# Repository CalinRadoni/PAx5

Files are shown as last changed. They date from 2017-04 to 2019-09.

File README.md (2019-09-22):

# PAx5

## Note

This repository is archived because I am building a version with better integration
in the [pax-devices](https://github.com/CalinRadoni/pax-devices) repository.

## Description

__PAx5__ is a home automation platform designed to be secure, stable and powerful.

__#__ Hardware is centered around an ultra-low-power ARM Cortex-M0+ and a sub-GHz radio.

__#__ For security:
- AEAD (_Authenticated Encryption with Associated Data_) using the 128 or 256 bits key ChaCha20 algorithm (the _new_ protocol used in HTTPS, TLS, OpenSSL, ...);
- Unique, random, session keys;
- Communication protocol designed to withstand the known attacks against these type of communications.

__#__ Stability is increased with:
- the radio module's power is generally enough to not require intermediary routers;
- designed for high availability, redundant, gateways.

### Dependencies

CMSIS

### Hardware details

MCU: STM32L051xx
Radio: RFM69HW
SPI FLASH Memory

Rendering and pinouts are in `Docs/PAx5_Base` and in `Docs/PAx5_EnvSensor`.

Environment sensor rendering:
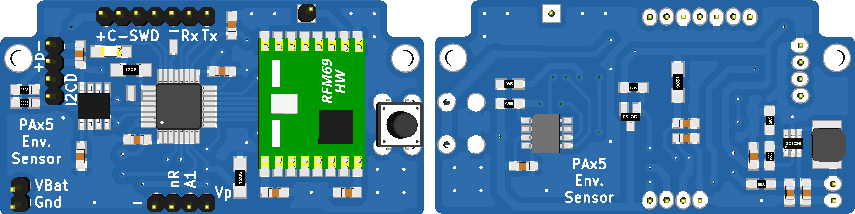
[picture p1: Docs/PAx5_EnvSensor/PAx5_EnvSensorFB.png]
env-sensor


and a photo of the sensor and base board:
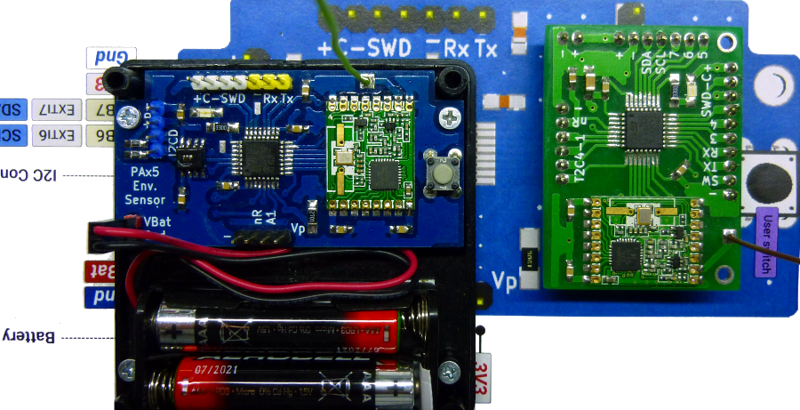
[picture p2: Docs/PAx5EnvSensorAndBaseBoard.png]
env-sensor


### Development Environment

Main tools used are:
- [KiCad EDA](http://kicad-pcb.org/)
- [Atollic TrueSTUDIO](https://atollic.com/truestudio/) Free Edition
- [Atom](https://atom.io/) editor

Supplementary tools:
- [Git](https://git-scm.com/)
- [STM32CubeMX](http://www.st.com/en/development-tools/stm32cubemx.html)
- [Inkscape](https://inkscape.org/en/)

### License

PAx5's software and documentation is released under the [GNU GPLv3](http://www.gnu.org/licenses/gpl-3.0.html) License. See the __LICENSE-GPLv3.txt__ file.

PAx5's hardware schematics are licensed under a [Creative Commons Attribution-ShareAlike 4.0 International License](http://creativecommons.org/licenses/by-sa/4.0/).
See the __LICENSE-CC-BY-SA-4.0.txt__ file.

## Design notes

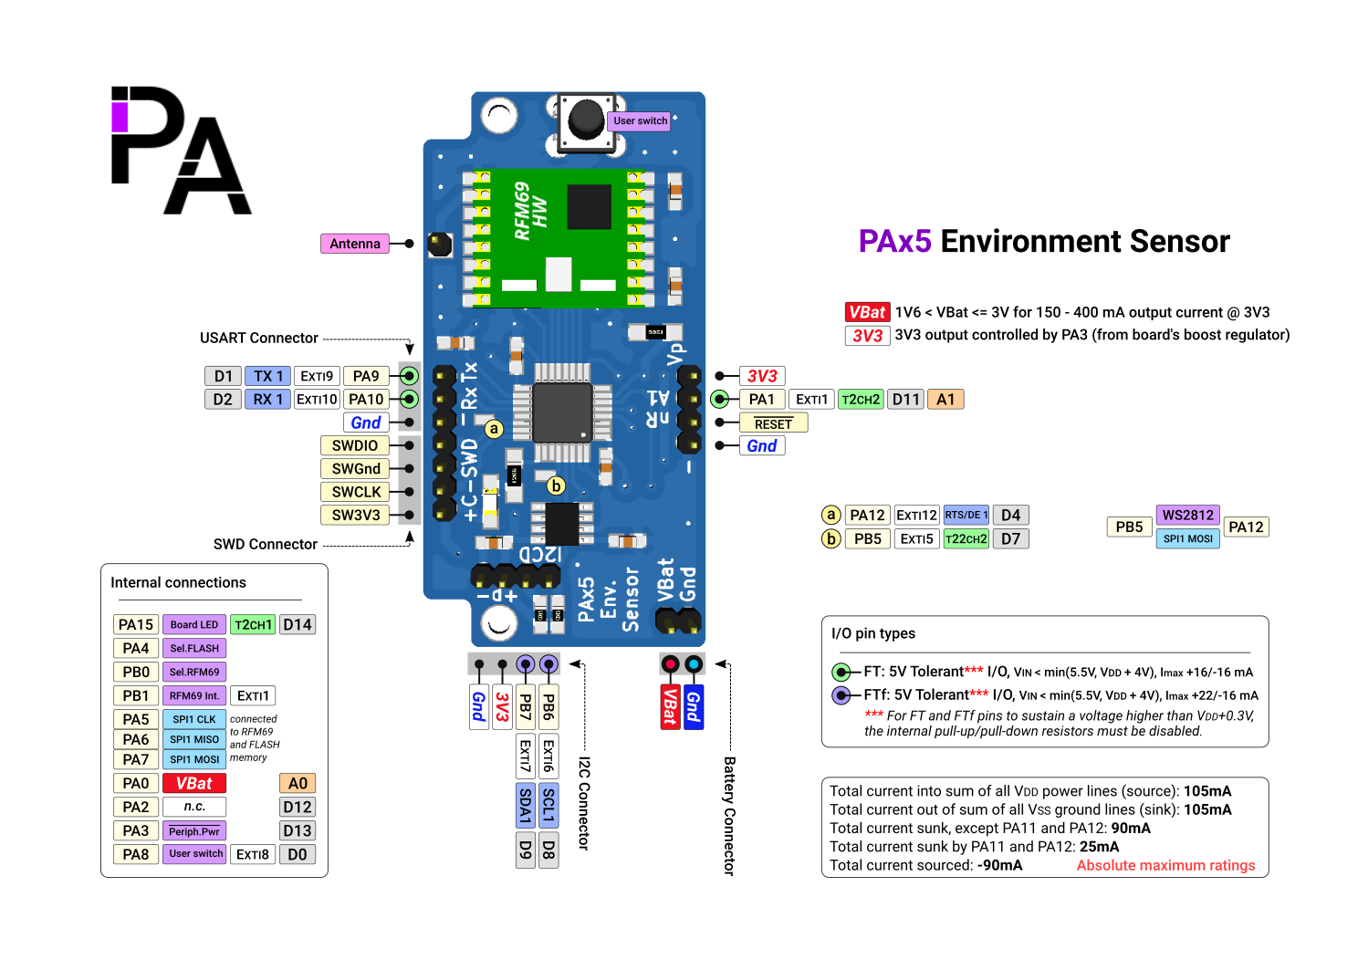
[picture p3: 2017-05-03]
Docs/PAx5_EnvSensor/PAx5_EnvSensor_Pinout.png

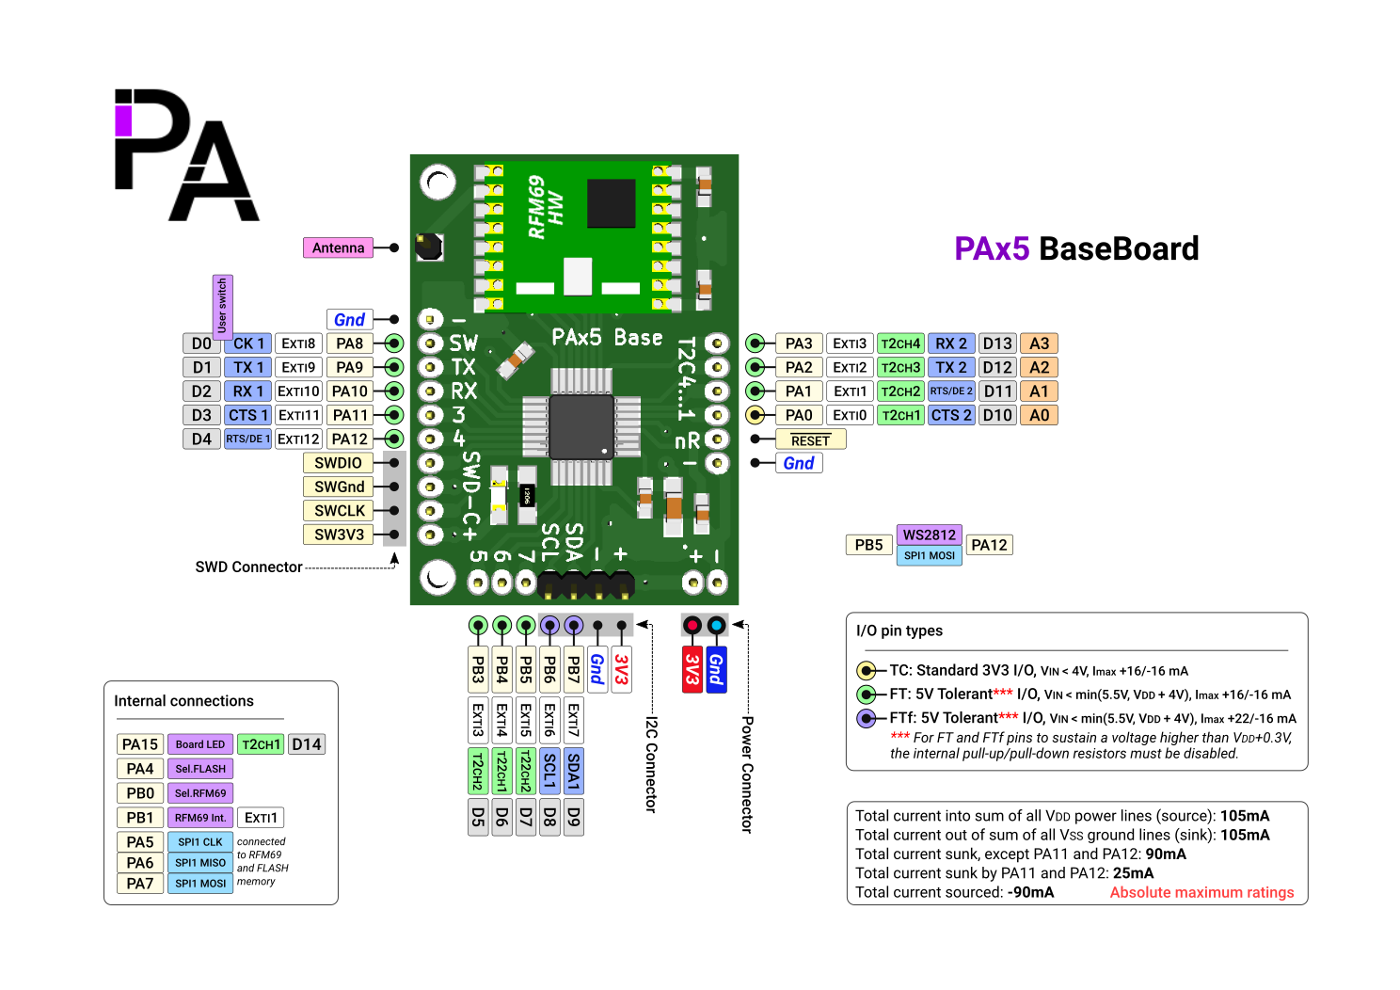
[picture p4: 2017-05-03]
Docs/PAx5_Base/PAx5_Base_Pinout.png

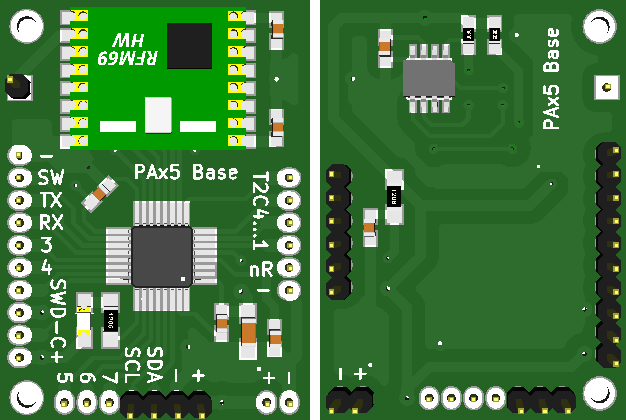
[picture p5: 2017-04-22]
Docs/PAx5_Base/PAx5_BaseFB.png

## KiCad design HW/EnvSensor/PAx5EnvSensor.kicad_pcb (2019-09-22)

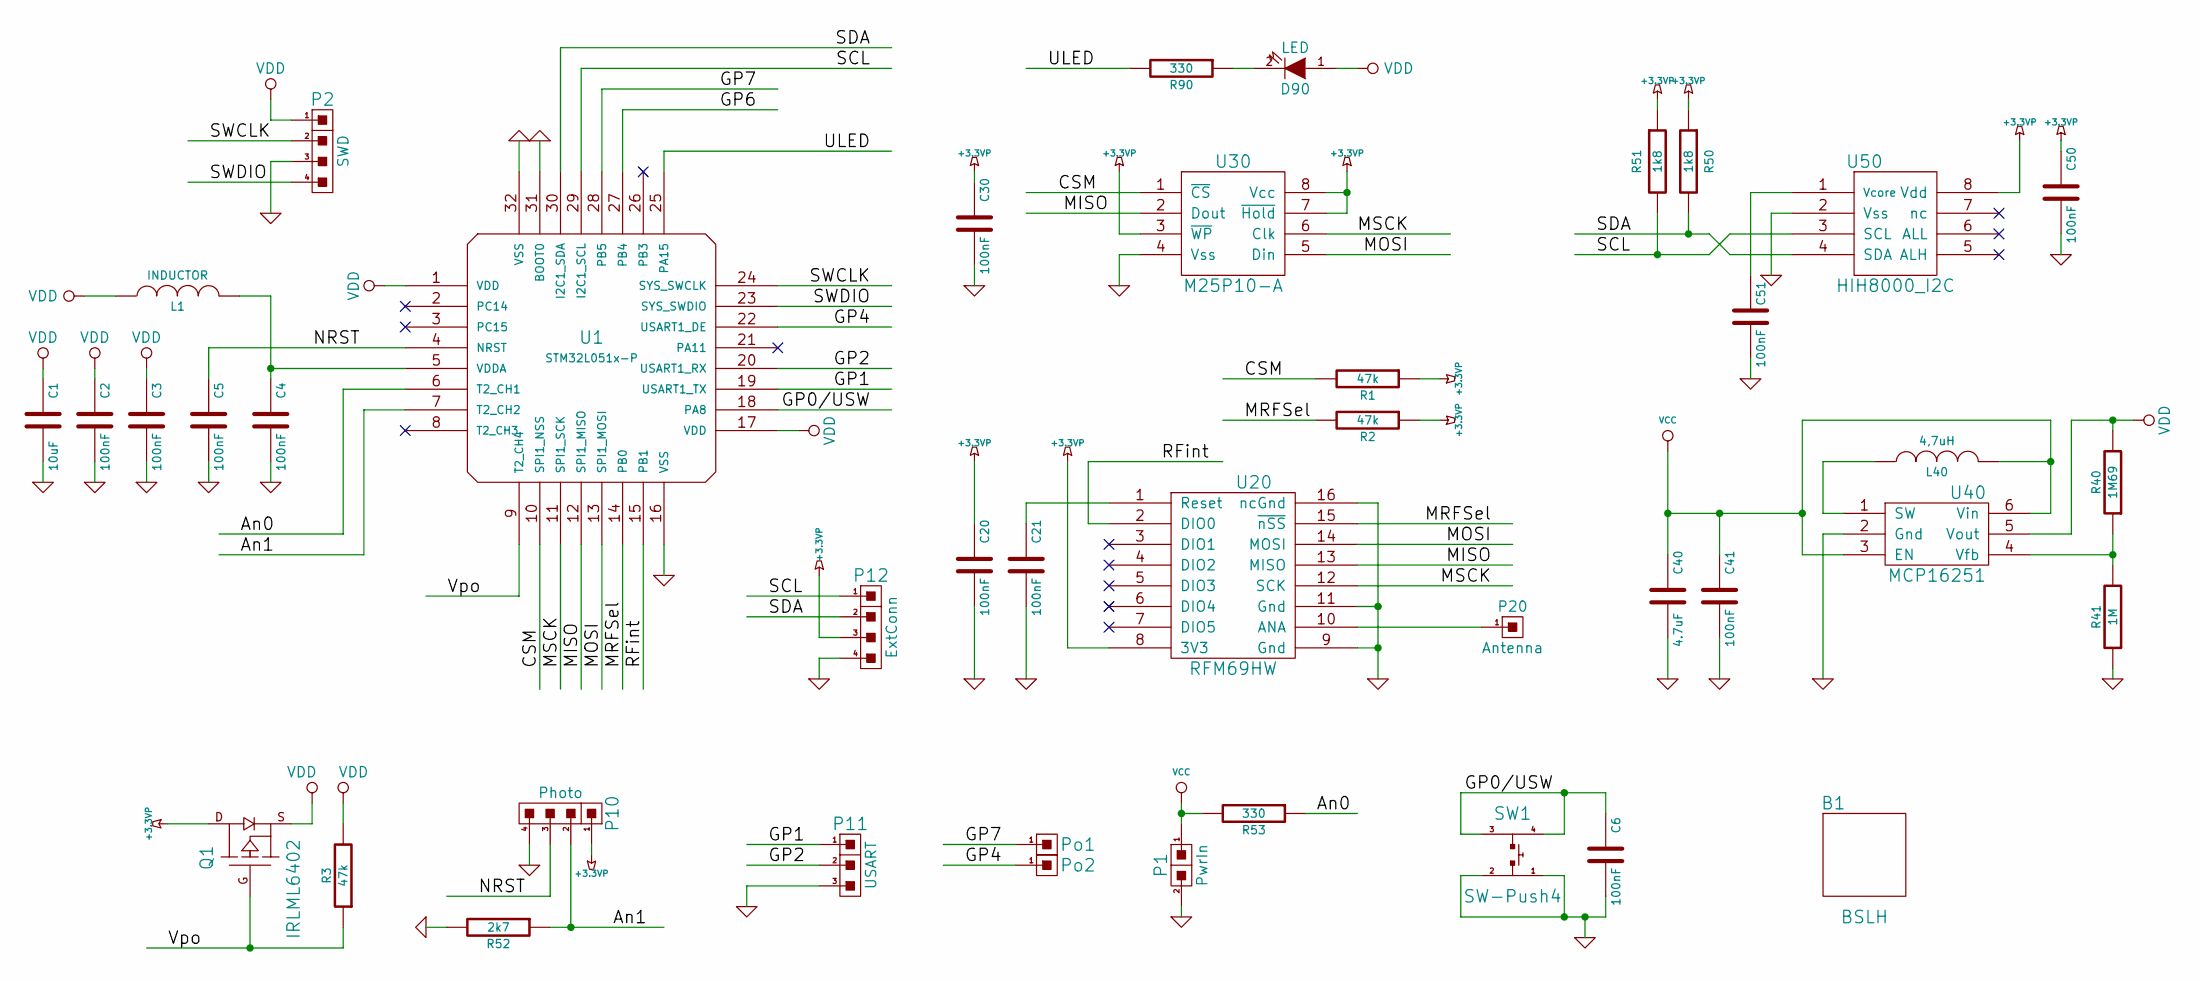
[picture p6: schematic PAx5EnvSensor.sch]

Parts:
B1: BSLH; Box-Sens-LH-NPTH
C1: 10uF; C_0805_HandSoldering
C2, C3, C4, C5, C6, C20, C21, C30, C41, C50, C51: 100nF; C_0805_HandSoldering
C40: 4.7uF; C_0805_HandSoldering
D90: LED; LED_1206_HandSoldering
L1: INDUCTOR; R_1206_HandSoldering
L40: 4,7uH; TYS50xx
P1: PwrIn; Pin_Header_Straight_1x02
P2: SWD; Pin_Header_Straight_1x04
P10: Photo; Pin_Header_Straight_1x04
P11: USART; Pin_Header_Straight_1x03
P12: ExtConn; Pin_Header_Straight_1x04
P20: Antenna; Pin_Header_Straight_1x01
Po1, Po2: PinTest-SMD
Q1: IRLML6402; SOT-23-calin
R1, R2, R3: 47k; R_0805_HandSoldering
R40: 1M69; R_0805_HandSoldering
R41: 1M; R_0805_HandSoldering
R50, R51: 1k8; R_0805_HandSoldering
R52: 2k7; R_1206_HandSoldering
R53: 330; R_0805_HandSoldering
R90: 330; R_1206_HandSoldering
SW1: SW-Push4; cSW-Push-4
U1: STM32L051x-P; cLQFP32-7-v2
U20: RFM69HW
U30: M25P10-A; SOIC-8-N
U40: MCP16251; SOT23-6
U50: HIH8000_I2C; HIH8000

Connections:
+3.3VP: C20.1, C30.1, C50.1, P10.1, P12.3, Q1.D, R1.1, R2.1, R50.1, R51.1, U20.8 (3V3), U30.3 (~WP), U30.7 (~Hold), U30.8 (Vcc), U50.8 (Vdd)
/An0: R53.1, U1.6 (T2_CH1)
/An1: P10.2, R52.1, U1.7 (T2_CH2)
/CSM: R1.2, U1.10 (SPI1_NSS), U30.1 (~CS)
/GP0/USW: C6.1, SW1.3, SW1.4, U1.18 (PA8)
/GP1: P11.1, U1.19 (USART1_TX)
/GP2: P11.2, U1.20 (USART1_RX)
/GP4: Po2.1, U1.22 (USART1_DE)
/GP7: Po1.1, U1.28 (PB5)
/MISO: U1.12 (SPI1_MISO), U20.13 (MISO), U30.2 (Dout)
/MOSI: U1.13 (SPI1_MOSI), U20.14 (MOSI), U30.5 (Din)
/MRFSel: R2.2, U1.14 (PB0), U20.15 (~nSS)
/MSCK: U1.11 (SPI1_SCK), U20.12 (SCK), U30.6 (Clk)
/NRST: C5.1, P10.3, U1.4 (NRST)
/RFint: U1.15 (PB1), U20.2 (DIO0)
/SCL: P12.1, R51.2, U1.29 (I2C1_SCL), U50.3 (SCL)
/SDA: P12.2, R50.2, U1.30 (I2C1_SDA), U50.4 (SDA)
/SWCLK: P2.2, U1.24 (SYS_SWCLK)
/SWDIO: P2.4, U1.23 (SYS_SWDIO)
/ULED: R90.2, U1.25 (PA15)
/Vpo: Q1.G, R3.1, U1.9 (T2_CH4)
GND: C1.2, C2.2, C3.2, C4.2, C5.2, C6.2, C20.2, C21.2, C30.2, C40.2, C41.2, C50.2, C51.2, P1.2, P2.3, P10.4, P11.3, P12.4, R41.1, R52.2, SW1.1, SW1.2, U1.16 (VSS), U1.31 (BOOT0), U1.32 (VSS), U20.9 (Gnd), U20.11 (Gnd), U20.16 (ncGnd), U30.4 (Vss), U40.2 (Gnd), U50.2 (Vss)
unnamed: C4.1, L1.2, U1.5 (VDDA)
unnamed: C21.1, U20.1 (Reset)
unnamed: C51.1, U50.1 (Vcore)
unnamed: D90.2 (K), R90.1
unnamed: L40.1, U40.1 (SW)
unnamed: P20.1, U20.10 (ANA)
unnamed: R40.1, R41.2, U40.4 (Vfb)
VCC: C40.1, C41.1, L40.2, P1.1, R53.2, U40.3 (EN), U40.6 (Vin)
VDD: C1.1, C2.1, C3.1, D90.1 (A), L1.1, P2.1, Q1.S, R3.2, R40.2, U1.1 (VDD), U1.17 (VDD), U40.5 (Vout)

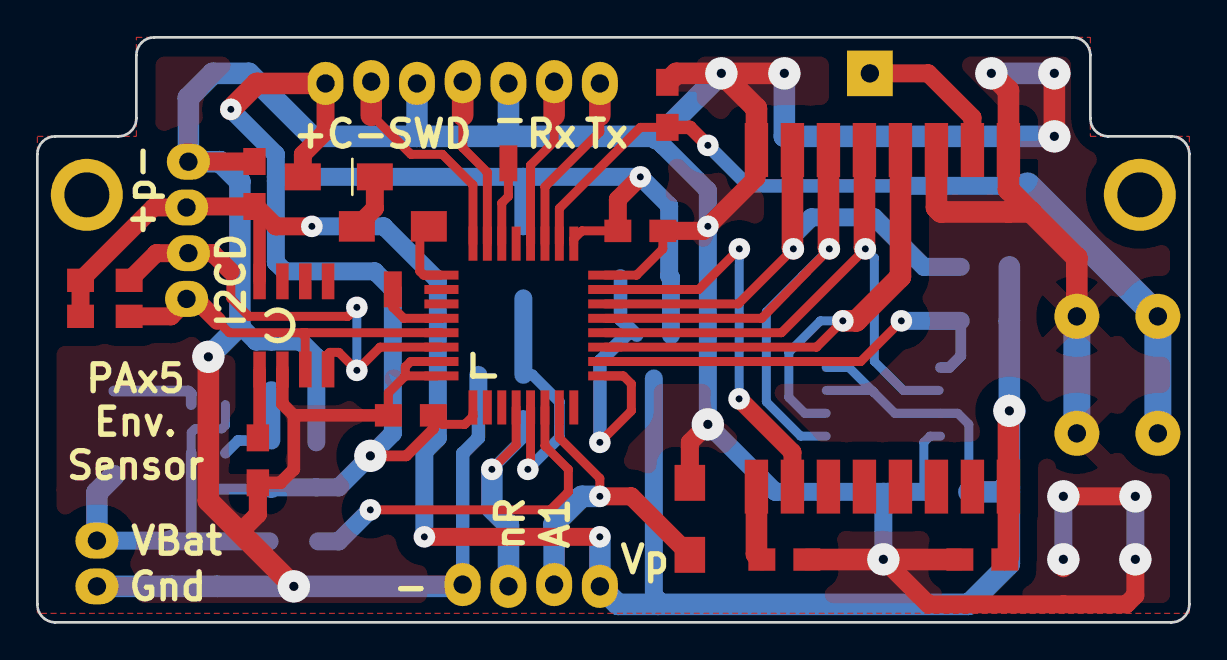
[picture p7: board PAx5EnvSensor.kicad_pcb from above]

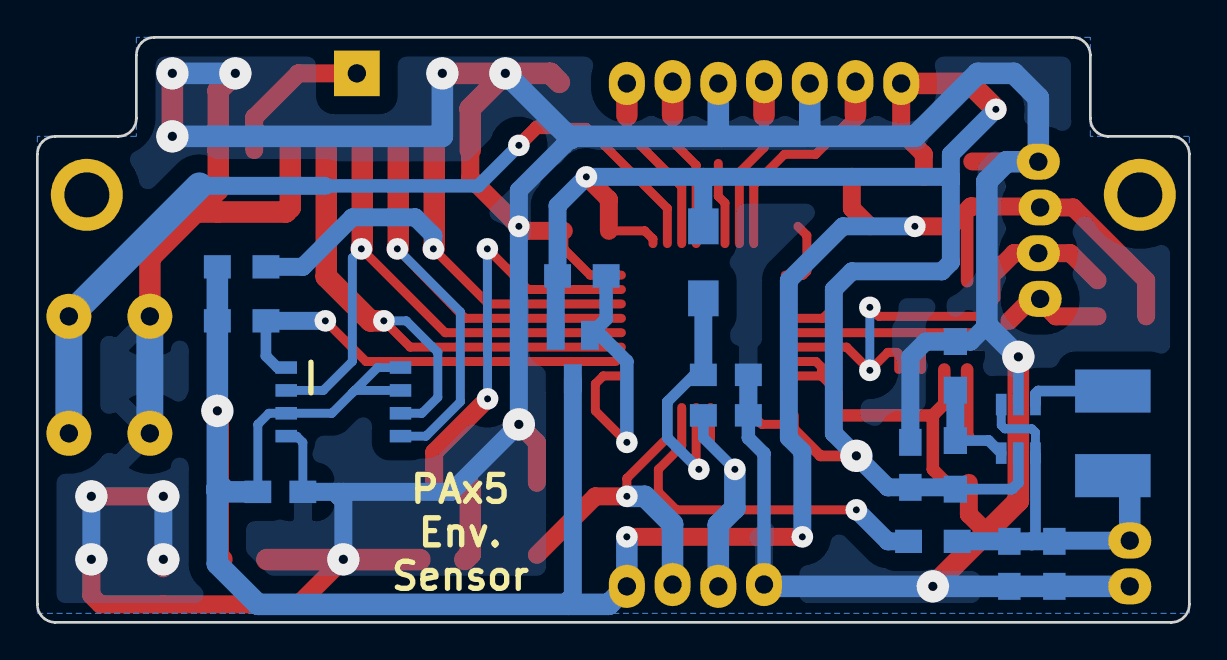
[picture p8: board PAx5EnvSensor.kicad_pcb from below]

Board: 2 copper layers, 64.0 x 32.5 mm, 42 parts (17 on the bottom side), 31 nets.

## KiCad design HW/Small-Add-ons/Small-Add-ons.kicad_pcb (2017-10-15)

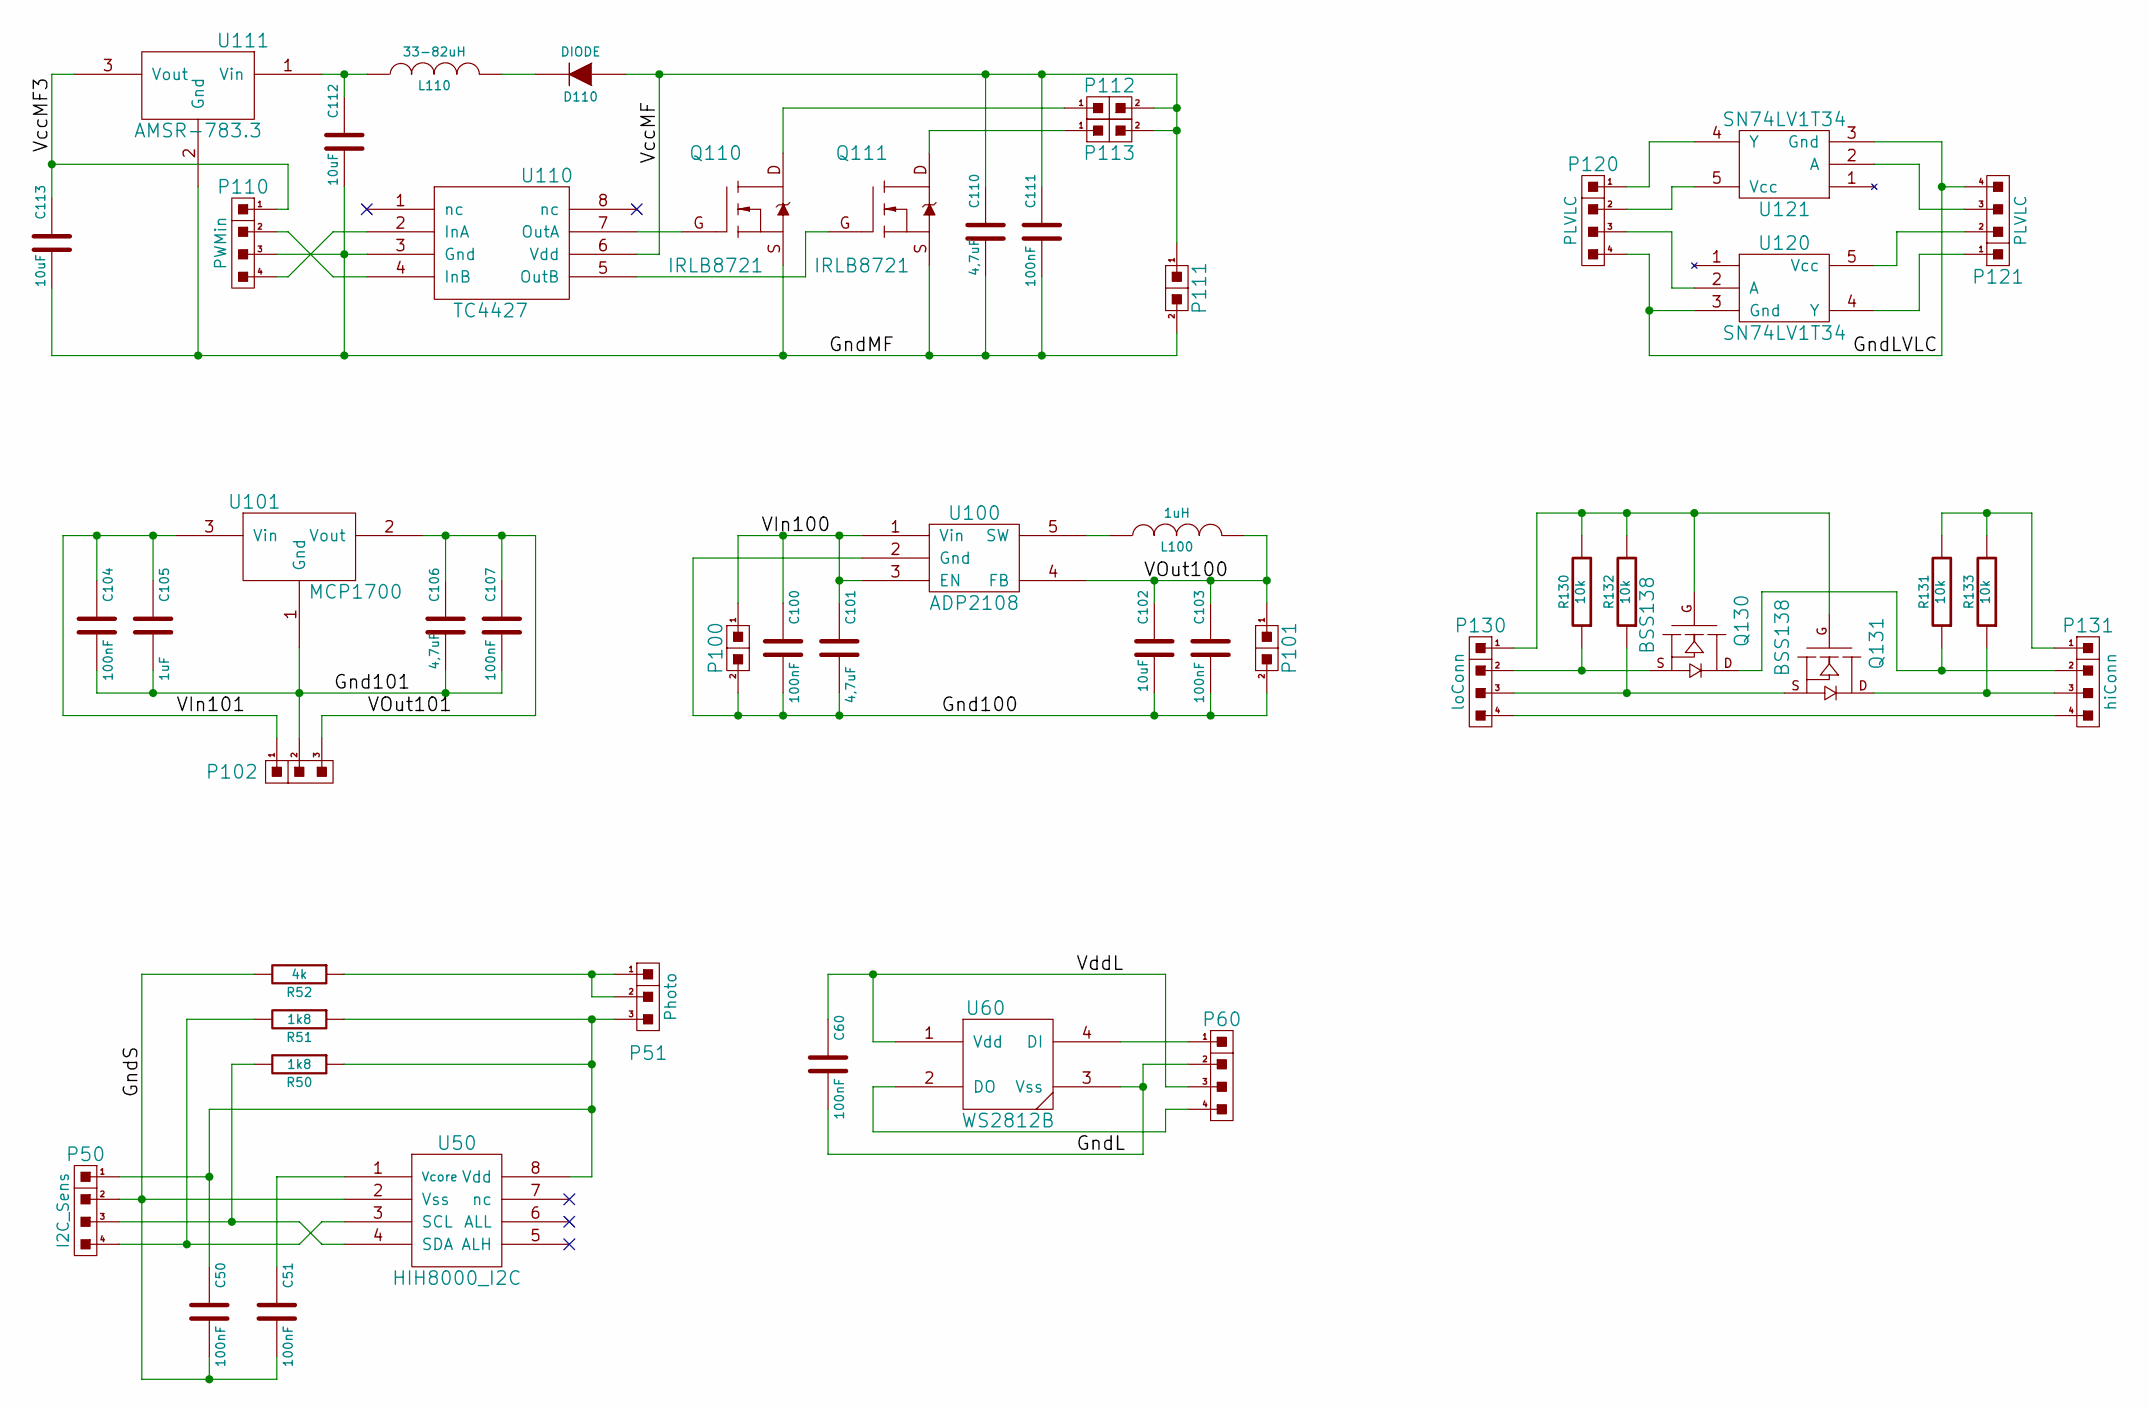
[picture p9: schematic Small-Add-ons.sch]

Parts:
C50, C51, C60, C100, C103, C104, C107, C111: 100nF; C_0805_HandSoldering
C101, C106, C110: 4,7uF; C_0805_HandSoldering
C102: 10uF; C_0805_HandSoldering
C105: 1uF; C_0805_HandSoldering
C112, C113: 10uF; C_1206_HandSoldering
D110: DIODE; DO-214AA-12
L100: 1uH; muRata-LQM2HPN1R0MJ0
L110: 33-82uH; COIL0608-0.033
P50: I2C_Sens; Pin_Header_Straight_1x04
P51: Photo; Pin_Header_Straight_1x03
P60: Pin_Header_Straight_1x04
P100: PVIn; Pin_Header_Straight_1x02
P101: PVOut; Pin_Header_Straight_1x02
P102: Pin_Header_Straight_1x03
P110: PWMin; Pin_Header_Straight_1x04
P111, P112, P113: PVOut; bornier2
P120, P121: PLVLC; Pin_Header_Straight_1x04
P130: loConn; Pin_Header_Straight_1x04
P131: hiConn; Pin_Header_Straight_1x04
Q110, Q111: IRLB8721; TO-220AB-GDS
Q130, Q131: BSS138; SOT-23-calin
R50, R51: 1k8; R_0805_HandSoldering
R52: 4k; R_1206_HandSoldering
R130, R131, R132, R133: 10k; R_0805_HandSoldering
U50: HIH8000_I2C; HIH8000
U60: WS2812B
U100: ADP2108; SOT23-5
U101: MCP1700; SOT23
U110: TC4427; SOIC-8-N
U111: AMSR-783.3; TO-220AB(SOT78)
U120, U121: SN74LV1T34; SOT23-5

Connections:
/Gnd100: C100.2, C101.2, C102.2, C103.2, P100.2, P101.2, U100.2 (Gnd)
/Gnd101: C104.2, C105.2, C106.2, C107.2, P102.2, U101.1 (Gnd)
/GndL: C60.2, P60.2, U60.3 (Vss)
/GndLVLC: P120.4, P121.4, U120.3 (Gnd), U121.3 (Gnd)
/GndMF: C110.2, C111.2, C112.2, C113.2, P110.3, P111.2, Q110.S, Q111.S, U110.3 (Gnd), U111.2 (Gnd)
/GndS: C50.2, C51.2, P50.2, R52.2, U50.2 (Vss)
/VIn100: C100.1, C101.1, P100.1, U100.1 (Vin), U100.3 (EN)
/VIn101: C104.1, C105.1, P102.1, U101.3 (Vin)
/VOut100: C102.1, C103.1, L100.2, P101.1, U100.4 (FB)
/VOut101: C106.1, C107.1, P102.3, U101.2 (Vout)
/VccMF: C110.1, C111.1, D110.1 (A), P111.1, P112.2, P113.2, U110.6 (Vdd)
/VccMF3: C113.1, P110.1, U111.3 (Vout)
/VddL: C60.1, P60.3, U60.1 (Vdd)
unnamed: C50.1, P50.1, P51.3, R50.1, R51.1, U50.8 (Vdd)
unnamed: C51.1, U50.1 (Vcore)
unnamed: C112.1, L110.1, U111.1 (Vin)
unnamed: D110.2 (K), L110.2
unnamed: L100.1, U100.5 (SW)
unnamed: P50.3, R50.2, U50.4 (SDA)
unnamed: P50.4, R51.2, U50.3 (SCL)
unnamed: P51.1, P51.2, R52.1
unnamed: P60.1, U60.4 (DI)
unnamed: P60.4, U60.2 (DO)
unnamed: P110.2, U110.4 (InB)
unnamed: P110.4, U110.2 (InA)
unnamed: P112.1, Q110.D
unnamed: P113.1, Q111.D
unnamed: P120.1, U121.4 (Y)
unnamed: P120.2, U121.5 (Vcc)
unnamed: P120.3, U120.2 (A)
unnamed: P121.1, U120.4 (Y)
unnamed: P121.2, U120.5 (Vcc)
unnamed: P121.3, U121.2 (A)
unnamed: P130.1, Q130.G, Q131.G, R130.2, R132.2
unnamed: P130.2, Q130.S, R130.1
unnamed: P130.3, Q131.S, R132.1
unnamed: P130.4, P131.4
unnamed: P131.1, R131.2, R133.2
unnamed: P131.2, Q130.D, R131.1
unnamed: P131.3, Q131.D, R133.1
unnamed: Q110.G, U110.7 (OutA)
unnamed: Q111.G, U110.5 (OutB)

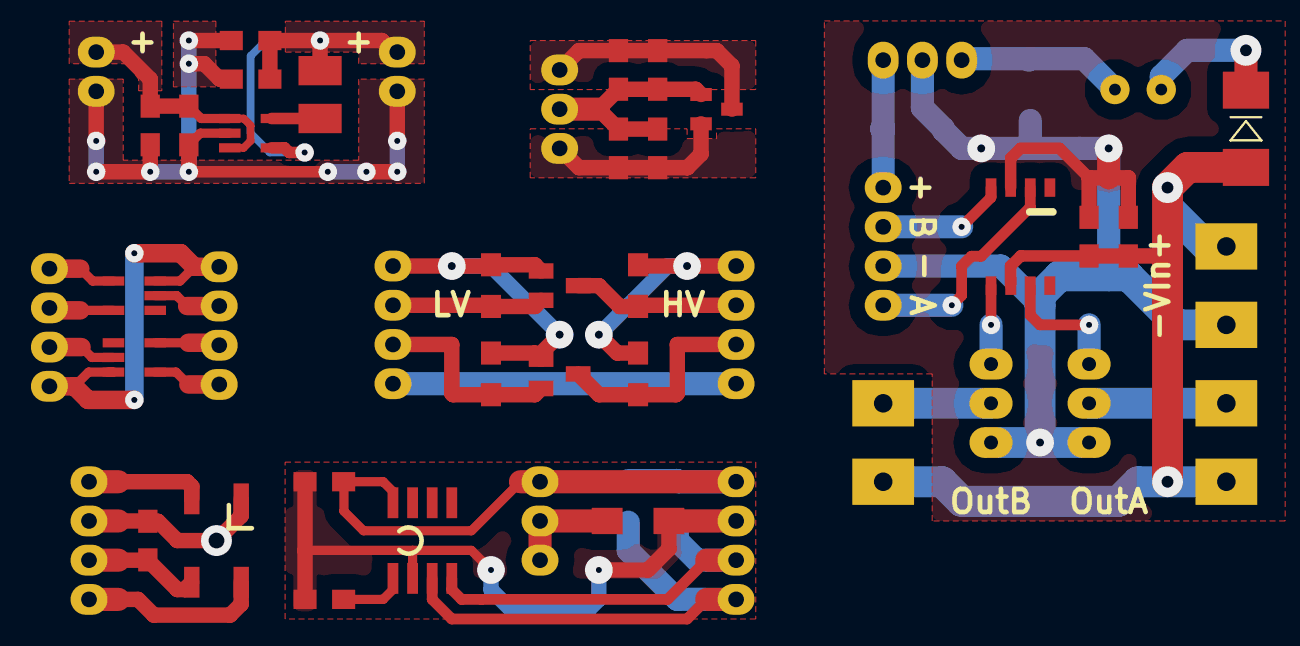
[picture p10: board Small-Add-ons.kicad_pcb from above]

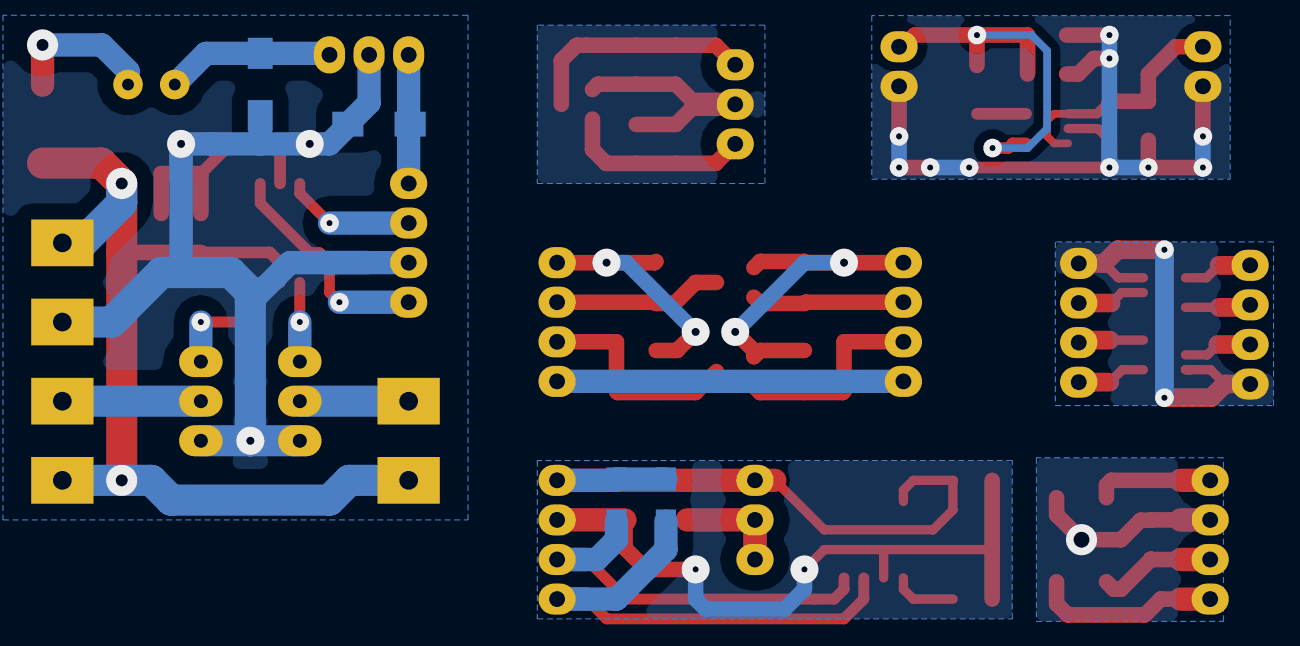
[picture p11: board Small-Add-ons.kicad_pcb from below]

Board: 2 copper layers, 51 parts (9 on the bottom side), 42 nets.

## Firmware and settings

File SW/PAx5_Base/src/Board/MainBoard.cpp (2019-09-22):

/**
This file is part of PAx5 (https://github.com/CalinRadoni/PAx5)
Copyright (C) 2016, 2017 by Calin Radoni

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
You should have received a copy of the GNU General Public License
along with this program.  If not, see <http://www.gnu.org/licenses/>.
*/

#include "MainBoard.h"

#include "cpu_Core.h"
#include "cpu_USART1.h"
#include "cpu_Info.h"
#include "cpu_SPI1.h"
#include "dev_ExternalFlash.h"
#include "dev_RFM69.h"
#include "cpu_Entropy.h"
#include "cpu_ADC.h"
#include "cpu_I2C.h"
#include "dev_LED.h"
#include "cpu_RTC.h"

namespace PAx5 {

// -----------------------------------------------------------------------------

FILEID(1)
#define LOG_CODE_START 1 // data = (uint16_t)(RCC->CSR >> 24)
#define LOG_CODE_CLOCK 2 // data = 1 for HSI timeout, 2 for PLL timeout, 3 for clock switching on PLL timeout

// -----------------------------------------------------------------------------

#define TIMEOUT_HSI         ((uint32_t)100U)  // 100 ms
#define TIMEOUT_PLL         ((uint32_t)100U)  // 100 ms
#define TIMEOUT_CLOCKSWITCH	((uint32_t)5000U) // 5 s

// -----------------------------------------------------------------------------

MainBoard board;

// -----------------------------------------------------------------------------

BoardDefinion::BoardDefinion() {}

/*
BoardDefinion& BoardDefinion::operator=(const BoardDefinion& src)
{
	if(&src == this) return *this; // self-assignment

	Use_USART            = src.Use_USART;
	Use_I2C              = src.Use_I2C;
	Use_I2C_Slave        = src.Use_I2C_Slave;
	ExtFLASH             = src.ExtFLASH;
	Radio_RFM69HW        = src.Radio_RFM69HW;
	PowerPeripherals_PA3 = src.PowerPeripherals_PA3;
	...

	return *this;
}
*/

void BoardDefinion::SetByType(BoardType type)
{
	Use_USART       = true;
	Use_I2C         = true; Use_I2C_Slave = false;
	ExtFLASH        = true;
	Radio_RFM69HW   = true;
	Use_WakeupTimer = false;

	PortC = 0x0000U;

	switch(type){
	case BoardType::PAx5_BaseBoard_CPU:
		PowerPeripherals_PA3 = false;
		PortA = 0x9F0FU; ///< PA0-PA3, PA8-PA11, PA12, PA15
		PortB = 0x00F8U; ///< PB3, PB4-PB7
		ExtFLASH      = false;
		Radio_RFM69HW = false;
		break;

	case BoardType::PAx5_BaseBoard:
		PowerPeripherals_PA3 = false;
		PortA = 0x9F0FU; ///< PA0-PA3, PA8-PA11, PA12, PA15
		PortB = 0x00F8U; ///< PB3, PB4-PB7
		break;

	case BoardType::PAx5_BaseBoardTester:
		PowerPeripherals_PA3 = false;
		PortA = 0x9F0FU; ///< PA0-PA3, PA8-PA11, PA12, PA15
		PortB = 0x00F8U; ///< PB3, PB4-PB7
		Use_WakeupTimer = true;
		break;

	case BoardType::PAx5_EnvSensor:
		PowerPeripherals_PA3 = true;
		PortA = 0x9602U; ///< PA1, PA9, PA10, PA12, PA15
		PortB = 0x0020U; ///< PB5
		Use_WakeupTimer = true;
		break;
	}
}

bool BoardDefinion::Use_SPI(void)
{
	if(Radio_RFM69HW) return true;
	if(ExtFLASH)      return true;
	return false;
}

bool BoardDefinion::Use_RTC(void)
{
	if(Use_WakeupTimer) return true;
	return false;
}

// -----------------------------------------------------------------------------

MainBoard::MainBoard()
{
	brdErr = Error::NotInitialized;
	radioIntFired = false;
	swPushed = false;
	swStart = swCounter = 0;
}

// -----------------------------------------------------------------------------

MainBoard::Error MainBoard::InitializeBoard(BoardDefinion& boardDef)
{
	uint16_t resetSource;

	// store reset informations from RCC_CSR register ...
	resetSource = (uint16_t)(RCC->CSR >> 24);
	// ... clear reset flags ...
	RCC->CSR |= RCC_CSR_RMVF;
	// ... and add an entry to HWLog
	hwLogger.AddEntry(FileID, LOG_CODE_START, resetSource);

	boardCapabilities = boardDef;

	brdErr = Error::OK;

	// system clock is configured for MSI 2.1 MHz after startup
	SysTick_Config(2100); // 1ms

	uint8_t clkCfg = sCPU.Startup_SetClock();
	switch(clkCfg){
		case 0:  /* OK */ break;
		case 1:  brdErr = Error::Clk_HSI_Timeout;     break;
		case 2:  brdErr = Error::Clk_PLL_Timeout;     break;
		case 3:  brdErr = Error::Clk_ClockSw_Timeout; break;
		default: brdErr = Error::Clk_UnknownError;    break;
	}
	SystemCoreClockUpdate();
	SysTick_Config(SystemCoreClock / 1000U);

	sCPU.cpuClocks.clockSYS = SystemCoreClock;
	sCPU.cpuClocks.Startup_SetValues();
	sCPU.cpuClocks.UpdateClockValues();

	if(brdErr == Error::OK){
		ConfigureGPIO();

		if(boardCapabilities.Use_USART) {
			if(!sUSART.ComputeUSARTDivider(sCPU.cpuClocks.clockUSART1, 115200)){
				brdErr = Error::USART;
			}
			else{
				if(!sUSART.Configure())
					brdErr = Error::USART;
			}
		}
	}

	if(brdErr == Error::OK){
		// power the peripherals if needed
		if(boardCapabilities.PowerPeripherals_PA3){
			GPIOA->BSRR = GPIO_BSRR_BR_3;
		}
	}

	if(brdErr == Error::OK){
		sSPI.Configure();
		sSPI.defaultSPISettings = true;

		ConfigureEXTI();

		if(boardCapabilities.ExtFLASH) {
			sExternalFlash.Initialize();
			sExternalFlash.PowerDown();
		}

		radioIntFired = 0;
		if(boardCapabilities.Radio_RFM69HW) {
			sRadio.initUseAFC = false;
			sRadio.Initialize();
			if(sRadio.interfaceError)
				brdErr = Error::Radio;
		}

	}

	if(brdErr == Error::OK){
		if(boardCapabilities.Use_RTC()){
			if(!sRTC.InitializeRTC()){
				brdErr = Error::RTC_Init;
			}
			else{
				if(boardCapabilities.Use_WakeupTimer){
					if(!sRTC.InitializeWakeupTimer()){
						brdErr = Error::WakeupTimer;
					}
				}
			}
		}
	}

	return brdErr;
}

// -----------------------------------------------------------------------------

void MainBoard::BlinkError(void){

	if(brdErr == Error::OK) return;

	uint8_t errIn = (uint8_t)brdErr;

	sLED.Blink(1000);
	while(errIn != 0){
		sLED.Blink(300);
		--errIn;
	}
}

// -----------------------------------------------------------------------------

void MainBoard::PeripheralsOn(void)
{
	if(boardCapabilities.PowerPeripherals_PA3){
		GPIOA->BSRR = GPIO_BSRR_BR_3;
	}
}

void MainBoard::PeripheralsOff(void)
{
	if(boardCapabilities.PowerPeripherals_PA3){
		GPIOA->BSRR = GPIO_BSRR_BS_3;
	}
}

// -----------------------------------------------------------------------------

void MainBoard::Sleep(void)
{
	//
}

void MainBoard::Standby(void)
{
	//
}

// -----------------------------------------------------------------------------
/** @brief GPIO Configuration
 *
 *  This function configures all GPIO:
 *     PA8 as input (UserSW), - EXTI8
 *     PA15 as output (UserLED),
 *     PA5, PA6 and PA7 for SPI1
 *     the pins required through the BoardDefinition object
 *     the other pins as analog
 */
void MainBoard::ConfigureGPIO(void)
{
	uint32_t val;

	/** Default values
	 *
	 * After reset:
	 * - PA4 (SPI1 NSS) default == 0  (input)
	 * - PA13 (SWDIO)   default == 10 (alternate)
	 * - PA14 (SWCLK)   default == 10 (alternate)
	 * - the others are default == 11 (analog mode)
	 */

	// Enable peripheral clock of GPIOx
	RCC->IOPENR |= RCC_IOPENR_GPIOAEN | RCC_IOPENR_GPIOBEN | RCC_IOPENR_GPIOCEN;

	// Configure GPIO pins PA0 - PA2, PA11, PA12 in analog mode
	val = GPIO_MODER_MODE0 | GPIO_MODER_MODE1 | GPIO_MODER_MODE2 | GPIO_MODER_MODE11 | GPIO_MODER_MODE12;
	if(!(boardCapabilities.PowerPeripherals_PA3)) {
		// configure PA3 in analog mode
		val |= GPIO_MODER_MODE3;
	}
	if(!(boardCapabilities.Use_SPI())){
		// configure PA5, PA6 and PA7 in analog mode
		val |= GPIO_MODER_MODE5 | GPIO_MODER_MODE6 | GPIO_MODER_MODE7;
	}
	if(!(boardCapabilities.Use_USART)) {
		// configure USART1 pins, PA9 and PA10, in analog mode
		val |= GPIO_MODER_MODE9 | GPIO_MODER_MODE10;
	}
	if(!(boardCapabilities.ExtFLASH)) {
		// configure PA4 in analog mode
		val |= GPIO_MODER_MODE4;
	}
	GPIOA->MODER |= val; // It is OK like this because GPIO_MODER_MODE* are all 1

	// configure peripheral power if needed
	if(boardCapabilities.PowerPeripherals_PA3){
		// PA3 (Peripheral power) configured as output push-pull, low speed, value HIGH
		GPIOA->MODER   = (GPIOA->MODER & ~(GPIO_MODER_MODE3)) | GPIO_MODER_MODE3_0;
		GPIOA->OTYPER  =  GPIOA->OTYPER & ~(GPIO_OTYPER_OT_3);
		GPIOA->OSPEEDR =  GPIOA->OSPEEDR & ~(GPIO_OSPEEDER_OSPEED3);
		GPIOA->BSRR    =  GPIO_BSRR_BS_3;
	}

	// Configure GPIO pins PB3 - PB5 as analog pins
	val = GPIO_MODER_MODE3 | GPIO_MODER_MODE4 | GPIO_MODER_MODE5;
	if(!(boardCapabilities.Radio_RFM69HW)) {
		// configure the pin for selecting the radio module, PB0, in analog mode
		val |= GPIO_MODER_MODE0;
		// configure the pin used as interrupt input from radio module, PB1, in analog mode
		val |= GPIO_MODER_MODE1;
	}
	if(!(boardCapabilities.Use_I2C)) {
		// Configure I2C1 pins, PB6 and PB7, as analog pins
		val |= GPIO_MODER_MODE6 | GPIO_MODER_MODE7;
	}
	GPIOB->MODER |= val; // It is OK like this because GPIO_MODER_MODE* are all 1

	// Configure GPIO pins PC14 PC15 as analog pins
	GPIOC->MODER |= GPIO_MODER_MODE14 | GPIO_MODER_MODE15;

	// No pull-up or pull-down
	GPIOA->PUPDR = 0x24000000; // default value, after reset
	GPIOB->PUPDR = 0;
	GPIOC->PUPDR = 0;

// ======= User switch
	// PA8 (UserSW) configured as input with pull-up
	GPIOA->MODER = GPIOA->MODER & ~(GPIO_MODER_MODE8);
	GPIOA->PUPDR = (GPIOA->PUPDR & ~(GPIO_PUPDR_PUPD8)) | GPIO_PUPDR_PUPD8_0;

// ======= User LED
	// PA15 (UserLED) configured as open-drain, low speed, value HIGH
	GPIOA->MODER   = (GPIOA->MODER & ~(GPIO_MODER_MODE15)) | GPIO_MODER_MODE15_0;
	GPIOA->OTYPER |= GPIO_OTYPER_OT_15;
	GPIOA->OSPEEDR = GPIOA->OSPEEDR & ~(GPIO_OSPEEDER_OSPEED15);
	GPIOA->BSRR    = GPIO_BSRR_BS_15;

// ======= USART1 pins
	if(boardCapabilities.Use_USART) {
		// PA9 and PA10 configured as alternate function
		GPIOA->MODER = (GPIOA->MODER & ~(GPIO_MODER_MODE9 | GPIO_MODER_MODE10)) | (GPIO_MODER_MODE9_1 | GPIO_MODER_MODE10_1);
		// Select the alternate function (AFR[0] is AFRL (pin0-7) and AFR[1] is AFRH (pin8-15))
		// UART1 is AF4 (0100) for PA9 and PA10
		GPIOA->AFR[1] = (GPIOA->AFR[1] & ~(0x00000FF0)) | 0x00000440;
	}

// ======= SPI slave select pins
	if(boardCapabilities.ExtFLASH) {
		// PA4 (SPI_SelMem) configured as output push-pull, high speed, value HIGH
		GPIOA->MODER   = (GPIOA->MODER & ~(GPIO_MODER_MODE4)) | GPIO_MODER_MODE4_0;
		GPIOA->OTYPER  =  GPIOA->OTYPER & ~(GPIO_OTYPER_OT_4);
		GPIOA->OSPEEDR = (GPIOA->OSPEEDR & ~(GPIO_OSPEEDER_OSPEED4)) | GPIO_OSPEEDER_OSPEED4_1;
		GPIOA->BSRR    =  GPIO_BSRR_BS_4;
	}
	if(boardCapabilities.Radio_RFM69HW) {
		// PB0 (SPI_SelRadio) configured as output push-pull, high speed, value HIGH
		GPIOB->MODER   = (GPIOB->MODER & ~(GPIO_MODER_MODE0)) | GPIO_MODER_MODE0_0;
		GPIOB->OTYPER  =  GPIOB->OTYPER & ~(GPIO_OTYPER_OT_0);
		GPIOB->OSPEEDR = (GPIOB->OSPEEDR & ~(GPIO_OSPEEDER_OSPEED0)) | GPIO_OSPEEDER_OSPEED0_1;
		GPIOB->BSRR    =  GPIO_BSRR_BS_0;
	}

// ======= SPI pins
	if(boardCapabilities.Use_SPI()){
		// PA5 = SPI1 Clock : Output push-pull, Very high speed, value LOW
		GPIOA->MODER   = (GPIOA->MODER & ~(GPIO_MODER_MODE5)) | GPIO_MODER_MODE5_0;
		GPIOA->OTYPER  =  GPIOA->OTYPER & ~(GPIO_OTYPER_OT_5);
		GPIOA->OSPEEDR =  GPIOA->OSPEEDR | GPIO_OSPEEDER_OSPEED5;
		GPIOA->BSRR    =  GPIO_BSRR_BR_5;
		// PA6 = SPI1 MISO : Input with pull-up
		GPIOA->MODER   =  GPIOA->MODER & ~(GPIO_MODER_MODE6);
		GPIOA->PUPDR   = (GPIOA->PUPDR & ~(GPIO_PUPDR_PUPD6)) | GPIO_PUPDR_PUPD6_0;
		// PA7 = SPI1 MOSI : Output push-pull, Very high speed, value LOW
		GPIOA->MODER   = (GPIOA->MODER & ~(GPIO_MODER_MODE7)) | GPIO_MODER_MODE7_0;
		GPIOA->OTYPER  =  GPIOA->OTYPER & ~(GPIO_OTYPER_OT_7);
		GPIOA->OSPEEDR =  GPIOA->OSPEEDR | GPIO_OSPEEDER_OSPEED7;
		GPIOA->BSRR    =  GPIO_BSRR_BR_7;
		// PA5, PA6 and PA7 configured as alternate function
		GPIOA->MODER   = (GPIOA->MODER & ~(GPIO_MODER_MODE5 | GPIO_MODER_MODE6 | GPIO_MODER_MODE7)) |
							(GPIO_MODER_MODE5_1 | GPIO_MODER_MODE6_1 | GPIO_MODER_MODE7_1);
		// Select the alternate function (AFR[0] is AFRL (pin0-7) and AFR[1] is AFRH (pin8-15))
		// SPI1 is AF0 (0000) for PA5, PA6 and PA7
		GPIOA->AFR[0]  = (GPIOA->AFR[0] & 0x000FFFFF);
	}

// ======= Interrupt pin connected to RFM69
	if(boardCapabilities.Radio_RFM69HW) {
		// PB1 (RadioInterrupt) configured as input with pull-down
		GPIOB->MODER = GPIOB->MODER & ~(GPIO_MODER_MODE1);
		GPIOB->PUPDR = (GPIOB->PUPDR & ~(GPIO_PUPDR_PUPD1)) | GPIO_PUPDR_PUPD1_1;
	}

// ======= I2C pins
	if(boardCapabilities.Use_I2C) {
		// PB6 - PB7 configured as open-drain, high speed, value HIGH and pull-up
		GPIOB->PUPDR   = (GPIOB->PUPDR & ~(GPIO_PUPDR_PUPD6 | GPIO_PUPDR_PUPD7)) |
							(GPIO_PUPDR_PUPD6_0 | GPIO_PUPDR_PUPD7_0);
		GPIOB->OTYPER |= GPIO_OTYPER_OT_6 | GPIO_OTYPER_OT_7;
		GPIOB->OSPEEDR = (GPIOB->OSPEEDR & ~(GPIO_OSPEEDER_OSPEED6 | GPIO_OSPEEDER_OSPEED7)) |
							(GPIO_OSPEEDER_OSPEED6_1 | GPIO_OSPEEDER_OSPEED7_1);
		// Select the alternate function (AFR[0] is AFRL (pin0-7) and AFR[1] is AFRH (pin8-15))
		// I2C1 is AF1 (0001) for PB6 and PB7
		GPIOB->AFR[0]  = (GPIOB->AFR[0] & 0x00FFFFFF) | 0x11000000;
		GPIOB->MODER   = (GPIOB->MODER & ~(GPIO_MODER_MODE6 | GPIO_MODER_MODE7)) |
							(GPIO_MODER_MODE6_1 | GPIO_MODER_MODE7_1);
	}
}

// -----------------------------------------------------------------------------

void MainBoard::ConfigureEXTI(void)
{
	// Enable SYSCFG clock
	RCC->APB2ENR |= RCC_APB2ENR_SYSCFGEN;

	// PA is the source for EXTI8 interrupt
	SYSCFG->EXTICR[2] = (SYSCFG->EXTICR[2] & ~(SYSCFG_EXTICR3_EXTI8)) | SYSCFG_EXTICR3_EXTI8_PA;

	EXTI->IMR  = EXTI->IMR  | EXTI_IMR_IM8;  // enable Line 8
	EXTI->RTSR = EXTI->RTSR | EXTI_RTSR_TR8; // enable rising edge
	EXTI->FTSR = EXTI->FTSR | EXTI_FTSR_TR8; // enable falling edge

	NVIC_SetPriority(EXTI4_15_IRQn, NVIC_PRIORITY_EXTI_4_15);
	NVIC_EnableIRQ(EXTI4_15_IRQn);
}

// -----------------------------------------------------------------------------

void MainBoard::EnableTIM6(void)
{
	// The counter counts from 0 to the auto-reload value (contents of the TIMx_ARR register),
	// then restarts from 0 and generates a counter overflow event.

	RCC->APB1ENR |= RCC_APB1ENR_TIM6EN;

	TIM6->CR1  = TIM_CR1_ARPE | TIM_CR1_URS | TIM_CR1_UDIS;
	TIM6->DIER = 0; // no interrupts
	TIM6->CR2  = 0;
	TIM6->SR   = TIM6->SR & ~(TIM_SR_UIF);
	TIM6->PSC  = 32000; // 1ms time base
	TIM6->ARR  = 0xFFFF;
	TIM6->EGR  = TIM6->EGR | TIM_EGR_UG; // update PSC, ARR, clear prescaler and counter

	/* To start:
	 *  - TIM6->ARR = milliseconds / reload cycle
	 *  - TIM6->EGR = TIM6->EGR | TIM_EGR_UG; // update PSC, ARR, clear prescaler and counter
	 * 	- set TIM6->CR1 |= TIM_CR1_CEN
	 */
}
void MainBoard::DisableTIM6(void)
{
	RCC->APB1ENR |= RCC_APB1ENR_TIM6EN;

	TIM6->CR1  = TIM6->CR1 & ~(TIM_CR1_CEN); // stop
	TIM6->DIER = 0; // no interrupts
	TIM6->SR   = TIM6->SR & ~(TIM_SR_UIF); // clear flags

	RCC->APB1ENR = RCC->APB1ENR & ~(RCC_APB1ENR_TIM6EN);
}

// -----------------------------------------------------------------------------

void MainBoard::RadioIntFired(void)
{
	radioIntFired = true;
}
void MainBoard::CheckRadioInterrupt(void)
{
	if(radioIntFired){
		radioIntFired = false;
		sRadio.HandleInterrupt();
	}
}

void MainBoard::HandlePushButtonInterrupt(void)
{
	if((GPIOA->IDR & GPIO_IDR_ID8) == 0){
		// switch is pressed
		swStart = sysTickCnt;
		swPushed = true;
	}
	else{
		// switch is released
		swPushed = false;
		swCounter = sysTickCnt - swStart;
	}
}

} /* namespace */

// -----------------------------------------------------------------------------
// STM32L0xx Peripherals Interrupt Handlers (peripheral interrupt handler's names are in startup_stm32l0xx.s)
// -----------------------------------------------------------------------------

extern "C" void EXTI0_1_IRQHandler(void)
{
	// EXTI flags are cleared by writing 1 to them (as the manual says)

	if((EXTI->PR & EXTI_PR_PR0) == EXTI_PR_PR0){
		EXTI->PR = EXTI_PR_PR0;
	}

	if((EXTI->PR & EXTI_PR_PR1) == EXTI_PR_PR1){
		EXTI->PR = EXTI_PR_PR1;
		if(PAx5::sSPI.defaultSPISettings){
			PAx5::sRadio.HandleInterrupt();
		}
		else{
			PAx5::board.RadioIntFired();
		}
	}
}

extern "C" void EXTI4_15_IRQHandler(void)
{
	// EXTI flags are cleared by writing 1 to them (as the manual says)

	if((EXTI->PR & EXTI_PR_PR8) == EXTI_PR_PR8){
		EXTI->PR = EXTI_PR_PR8;

		PAx5::board.HandlePushButtonInterrupt();
	}
}

// -----------------------------------------------------------------------------

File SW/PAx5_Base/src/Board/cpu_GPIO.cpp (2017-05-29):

/**
This file is part of PAx5 (https://github.com/CalinRadoni/PAx5)
Copyright (C) 2016, 2017 by Calin Radoni

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
You should have received a copy of the GNU General Public License
along with this program.  If not, see <http://www.gnu.org/licenses/>.
*/

#include "cpu_GPIO.h"

namespace PAx5 {

// -----------------------------------------------------------------------------

FILEID(10)
#define LOG_CODE_AttachToPin  1 // data = the wrong GPIOx
#define LOG_CODE_SetMode      2 // data = (uint16_t)pinNumber
#define LOG_CODE_SetModeSpeed 3 // data = 0
#define LOG_CODE_SetModeMode  4 // data = 0
#define LOG_CODE_SetModePull  5 // data = 0
#define LOG_CODE_GetMode      6 // data = (uint16_t)pinNumber
#define LOG_CODE_SetPin       7 // data = (uint16_t)pinNumber
#define LOG_CODE_ResetPin     8 // data = (uint16_t)pinNumber
#define LOG_CODE_GetPin       9 // data = (uint16_t)pinNumber

// -----------------------------------------------------------------------------

CPU_GPIO::CPU_GPIO() { }

CPU_GPIO::~CPU_GPIO() { }

// -----------------------------------------------------------------------------

void CPU_GPIO::AttachToPin(uint8_t pinID)
{
	pinNumber = pinID & 0x0F;

	uint8_t id = pinID & 0xF0;
	switch(id){
		case 0:  GPIOx = GPIOA; break;
		case 1:  GPIOx = GPIOB; break;
		case 2:  GPIOx = GPIOC; break;
		default:
			GPIOx = nullptr;
			hwLogger.AddEntry(FileID, LOG_CODE_AttachToPin, (uint16_t)id);
			break;
	}
}

// -----------------------------------------------------------------------------

bool CPU_GPIO::SetMode(const CPU_GPIO_Definition& pinDefinition)
{
	if((GPIOx == nullptr) || (pinNumber > 0x0F)){
		hwLogger.AddEntry(FileID, LOG_CODE_SetMode, (uint16_t)pinNumber);
		return false;
	}

	uint32_t tmp, val;

	/** GPIO alternate function registers,
	 * 4 bits / pin
	 * GPIOx->AFR[0] = GPIOx->AFRL (address offset 0x20), pins 0 - 7
	 * GPIOx->AFR[1] = GPIOx->AFRH (address offset 0x24), pins 8 - 15
	 *
	 * GPIOx_AFRL[31:28] = AFSEL7[3:0]  ... GPIOx_AFRL[3:0] = AFSEL0[3:0]
	 * GPIOx_AFRH[31:28] = AFSEL15[3:0] ... GPIOx_AFRH[3:0] = AFSEL8[3:0]
	 */
	// if alternate function, set it
    if((pinDefinition.mode == PinMode::Alternate) || (pinDefinition.mode == PinMode::AlternateOD)){
    	val = (uint32_t)(pinDefinition.altFunction & 0x0F);

		uint32_t pinNumberAFRL = pinNumber & (uint32_t)0x07U;
		tmp = GPIOx->AFR[pinNumber >> 3U];
		tmp &= ~(GPIO_AFRL_AFRL0_Msk << (pinNumberAFRL * 4U));
		tmp |= (val << (pinNumberAFRL * 4U));
		GPIOx->AFR[pinNumber >> 3U] = tmp;
    }

    /** GPIO port output speed register and GPIO port output type register
     * 2 bits/pin
     * GPIOx_OSPEEDR[31:30] = OSPEED15[1:0] ... GPIOx_OSPEEDR[1:0] = OSPEED0[1:0]
     * 1 bit/pin
     * GPIOx_OTYPER[15] = OT15 ... GPIOx_OTYPER[0] = OT0
     */
	// if output or alternate ...
    if((pinDefinition.mode == PinMode::Output) || (pinDefinition.mode == PinMode::OutputOD) ||
    		(pinDefinition.mode == PinMode::Alternate) || (pinDefinition.mode == PinMode::AlternateOD)){
    	// ... set the speed ...
		switch(pinDefinition.speed){
			case PinSpeed::Low:      val = 0U; break;
			case PinSpeed::Medium:   val = 1U; break;
			case PinSpeed::High:     val = 2U; break;
			case PinSpeed::VeryHigh: val = 3U; break;
			default:
				val = 0U; // default to low speed
				hwLogger.AddEntry(FileID, LOG_CODE_SetModeSpeed, 0);
				break;
		}
		tmp = GPIOx->OSPEEDR;
		tmp &= ~(GPIO_OSPEEDER_OSPEED0 << (pinNumber * 2U));
		tmp |= (val << (pinNumber * 2U));
		GPIOx->OSPEEDR = tmp;

		// ... and output type
		tmp= GPIOx->OTYPER;
		tmp &= ~(GPIO_OTYPER_OT_0 << pinNumber) ;
		if((pinDefinition.mode == PinMode::OutputOD) || (pinDefinition.mode == PinMode::AlternateOD))
			tmp |= (1U << pinNumber);
		GPIOx->OTYPER = tmp;
    }

    /** GPIO port mode register
     * 2 bits/pin
     * GPIOx_MODER[31:30] = MODE15[1:0] ... GPIOx_MODER[1:0] = MODE0[1:0]
     */
	// set the mode
    switch(pinDefinition.mode){
    	case PinMode::Analog:      val = 3U; break;
    	case PinMode::Input:       val = 0U; break;
    	case PinMode::Output:      val = 1U; break;
    	case PinMode::OutputOD:    val = 1U; break;
    	case PinMode::Alternate:   val = 2U; break;
    	case PinMode::AlternateOD: val = 2U; break;
    	default:
    		val = 3U; // default to Analog
    		hwLogger.AddEntry(FileID, LOG_CODE_SetModeMode, 0);
    		break;
    }
    tmp = GPIOx->MODER;
    tmp &= ~(GPIO_MODER_MODE0 << (pinNumber * 2U));
    tmp |= (val << (pinNumber * 2U));
    GPIOx->MODER = tmp;
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

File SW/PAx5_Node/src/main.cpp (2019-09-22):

/**
This file is part of PAx5 (https://github.com/CalinRadoni/PAx5)
Copyright (C) 2016, 2017 by Calin Radoni

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
You should have received a copy of the GNU General Public License
along with this program.  If not, see <http://www.gnu.org/licenses/>.
*/

#include "version.h"
#include "Node_Config.h"
#include "NetWorker.h"

#include "MainBoard.h"
#include "cpu_Entropy.h"
#include "cpu_I2C.h"
#include "cpu_Text.h"

#include "dev_LED.h"
#include "dev_HIHSensor.h"
#include "dev_RFM69.h"


// -----------------------------------------------------------------------------

PAx5Node::Node_Config nodeConfiguration;
PAx5CommProtocol::NetWorker nodeProtocol;
PAx5CommProtocol::NetWorker::RXCheck chkRes;
PAx5CommProtocol::TimedSlot *nodeTS;

// -----------------------------------------------------------------------------

int main(void)
{
	PAx5::BoardDefinion boardDefinition;
	boardDefinition.SetByType(PAx5::BoardDefinion::BoardType::PAx5_BaseBoard);

	if(PAx5::board.InitializeBoard(boardDefinition) != PAx5::MainBoard::Error::OK){
		PAx5::board.BlinkError();
		while(1){ /* infinite loop */ }
	}

	uint32_t timeStart, timeDelta, timeQ;
	uint8_t i;

	PAx5::DEV_HIHSensor hihSensor;
	uint16_t sH, sT;

	timeStart = PAx5::sysTickCnt;

	PAx5::sLED.ModeBlink(300, 300, 3);

	PAx5::entropy.CollectStart();

	PAx5::sTextOutput.InitBuffer();

	nodeConfiguration.ReadConfigInfo();
	if((nodeConfiguration.configInfo.verHi == 0) && (nodeConfiguration.configInfo.verLo == 0)) {
		// no configuration set in EEPROM, create a default one
		nodeProtocol.commProtocol.SetDefaultKey(&nodeProtocol.netCtx);
		nodeConfiguration.WriteKey((uint32_t*)&nodeProtocol.netCtx.key);
		nodeConfiguration.configInfo.address = PAx5CommProtocol::AddressClass::Address_NONE;
		nodeConfiguration.WriteFrequency((uint32_t)864000000);

		PAx5::sTextOutput.FormatAndOutputString("Default configuration created.\r\n");
	}
	if((nodeConfiguration.configInfo.verHi != SW_VER_MAJOR) || (nodeConfiguration.configInfo.verLo != SW_VER_MINOR)) {
		// current configuration in EEPROM must be updated
		nodeConfiguration.configInfo.verHi = SW_VER_MAJOR;
		nodeConfiguration.configInfo.verLo = SW_VER_MINOR;
		nodeConfiguration.WriteConfigInfo();
	}


	nodeConfiguration.configInfo.address = 7;


	nodeProtocol.Initialize(nodeConfiguration.configInfo.address, nodeConfiguration.ReadFrequency());
	nodeConfiguration.ReadKey((uint32_t*)&nodeProtocol.netCtx.key);
	PAx5::sRadio.SetMode(PAx5::RM_RX);

	PAx5::sTextOutput.FormatAndOutputString("PAx5 Node version %d.%d\r\n", nodeConfiguration.configInfo.verHi, nodeConfiguration.configInfo.verLo);
	PAx5::sTextOutput.FormatAndOutputString("Address: %d\r\n", nodeConfiguration.configInfo.address);
	PAx5::sTextOutput.FormatAndOutputString("Frequency: %d Hz\r\n", nodeConfiguration.ReadFrequency());
	PAx5::sTextOutput.FormatAndOutputString("Key: ");
	for(i=0; i<4; i++)
		PAx5::sTextOutput.FormatAndOutputString(" %8x", nodeProtocol.netCtx.key[i]);
	PAx5::sTextOutput.FormatAndOutputString("\r\n");
	PAx5::sTextOutput.Flush();

	timeQ = 0;

	while(1){
		// handle radio communication
		if(PAx5::sRadio.packetReceived){
			PAx5::sRadio.packetReceived = false;
			chkRes = nodeProtocol.CheckReceivedPacket();
			PAx5::sTextOutput.FormatAndOutputString("rx: %d\r\n", (uint8_t)chkRes); PAx5::sTextOutput.Flush();
			switch(chkRes){
			case PAx5CommProtocol::NetWorker::RXCheck::PacketOK:
				/* Received a data packet
				 * The communication slot is netWorker.dataPeer
				 * The data is in netWorker.commProtocol.packetRX[CP_PACKET_HDR_Length_POS]
				 */
				break;

			case PAx5CommProtocol::NetWorker::RXCheck::ReqAckReceived:
				/* REQ+ACK received, start sending data */
				nodeTS = nodeProtocol.dataPeer;

				PAx5::sTextOutput.FormatAndOutputString("REQ+ACK received\r\n", (uint8_t)chkRes); PAx5::sTextOutput.Flush();

				if(hihSensor.ReadData() == PAx5::DEV_HIHSensor::Status::DATA_OK){
					sH = hihSensor.GetHumidity();
					sT = hihSensor.GetTemperature();
					PAx5::sTextOutput.FormatAndOutputString("Data: %d %%RH %d degC", sH/10, (sT-2731)/10); PAx5::sTextOutput.Flush();
				}
				else{ sH = sT = 0xEEEE; }

				nodeProtocol.commProtocol.packetTX[PAx5CommProtocol::CP_PACKET_HEADER_LEN]     = (uint8_t)(sH >> 8);
				nodeProtocol.commProtocol.packetTX[PAx5CommProtocol::CP_PACKET_HEADER_LEN + 1] = (uint8_t)(sH & 0xFF);
				nodeProtocol.commProtocol.packetTX[PAx5CommProtocol::CP_PACKET_HEADER_LEN + 2] = (uint8_t)(sT >> 8);
				nodeProtocol.commProtocol.packetTX[PAx5CommProtocol::CP_PACKET_HEADER_LEN + 3] = (uint8_t)(sT & 0xFF);
				nodeProtocol.commProtocol.CreateDataPacket(nodeTS, 4, true);

				if(nodeProtocol.SendPacket()){
					nodeTS->UpdateTimeSlotAckWait(CP_TIME_WAIT_ACK);
					PAx5::sTextOutput.FormatAndOutputString("Data sent\r\n");
				}
				else {
					nodeTS->RestartTimeSlot(0);
					PAx5::sTextOutput.FormatAndOutputString("Failed to send data, RSSI = %d !\r\n", PAx5::sRadio.packetReceivedRSSI);
				}
				PAx5::sTextOutput.Flush();
				break;

			case PAx5CommProtocol::NetWorker::RXCheck::AckReceived:
				/* ACK received, continue sending data or close the timeslot if done */
				nodeTS = nodeProtocol.dataPeer;

				PAx5::sTextOutput.FormatAndOutputString("ACK received\r\n", (uint8_t)chkRes); PAx5::sTextOutput.Flush();

				nodeTS->RestartTimeSlot(0);
				break;

			case PAx5CommProtocol::NetWorker::RXCheck::AddrRequest:
				break;

			case PAx5CommProtocol::NetWorker::RXCheck::Bcast:
				break;

			default:
				break;
			}
			PAx5::sRadio.SetMode(PAx5::RM_RX);
		}

		// decrease time in sLED and communication slots
		if(timeStart != PAx5::sysTickCnt){
			timeDelta = PAx5::sysTickCnt - timeStart;
			timeStart = PAx5::sysTickCnt;

			PAx5::sLED.Pulse(timeDelta);
			nodeProtocol.DecreaseTimeSlots(timeDelta);

			if(timeDelta < timeQ) timeQ -= timeDelta;
			else{
				nodeTS = nodeProtocol.GetFreeSlot(PAx5CommProtocol::AddressClass::Address_Gateway);
				if(nodeTS != NULL){
					timeQ = 3000;

					PAx5::sLED.ModeOn(200);

					hihSensor.ReadInit();

					nodeTS->peerAddress = PAx5CommProtocol::AddressClass::Address_Gateway;
					nodeProtocol.commProtocol.CreateRequestPacket(nodeTS, &nodeProtocol.netCtx);
					if(nodeProtocol.SendPacket()) PAx5::sTextOutput.FormatAndOutputString("RSSI = %d, REQ sent\r\n", PAx5::sRadio.packetReceivedRSSI);
					else                       PAx5::sTextOutput.FormatAndOutputString("Failed to send REQ, RSSI = %d !\r\n", PAx5::sRadio.packetReceivedRSSI);
					PAx5::sTextOutput.Flush();

					PAx5::sRadio.SetMode(PAx5::RM_RX);
				}
			}
		}
	}
}

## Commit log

2017-05-03 Coding and commenting style update
    [PAx5EnvSensor.sch]
2017-05-29 License info added to .h and .cpp files and README update
    [Small-Add-ons.kicad_pcb]
2017-06-03 TSL2561 driver, not yet complete
2017-06-03 Updated .gitignore to exclude KiCad's autosave files
2017-06-06 corrected and tested WriteAndRead function for I2C repeated start
    [cpu_I2C.cpp]
2017-06-11 Added CPU_Core to handle clock and power modules
2017-06-12 Added push button handling code
2017-06-14 Added CPU_RTC for basic RTC and wake up timer functions
2017-06-18 Corrected CPU_Core, created a test function for CPU_Core and wake up timer (in CPU_RTC). Sleep, Stop and Standby mode tested OK.
    [cpu_Core.cpp]
2017-07-21 Added a photo with the sensor and the base board.
2017-10-15 Added pin names for level convertor board
    [Small-Add-ons.kicad_pcb]
2017-10-15 RTC prescaler changed to create 1 Hz RTC clock from LSI oscillator. Improved doc from involved files and updated the test code.
2019-09-22 Archiving the repository
    [PAx5EnvSensor.kicad_pcb, PAx5EnvSensor.sch]

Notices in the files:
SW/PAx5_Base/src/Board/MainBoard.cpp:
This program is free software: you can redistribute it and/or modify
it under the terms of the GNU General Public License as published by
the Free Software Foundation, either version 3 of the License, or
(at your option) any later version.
